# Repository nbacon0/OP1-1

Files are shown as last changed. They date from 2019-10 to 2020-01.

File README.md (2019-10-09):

The OP1:1 project is our effort to address an urgent need in the digital preservation community, namely that optical media (CDs, DVDS, etc.) are almost 40 years old, and are failing at an alarming rate: they're delaminating, suffering from disc rot and a slew of other issues.

Our proposed solution is a (completely open source) device to directly sample the laser as its reading the disc and storing this (very large) raw dump for safe-keeping and process later. The benefit of this approach is that it can be agnostic to the encoding of the discs. The same device that can preserve audio discs could be used to preserve video discs, photo discs, and other proprietary formats.
    
# Current Status
This project is currently months away from an initial release: parts have been ordered by the small group of volunteers and current resources regarding control of the OPU are being slowly assembled from parties that have engaged in research not directly addressing our need, but are still directly applicable to the goals outlined above.

###### Disclaimer
None of the below projects or resources are associated with the OP1:1 Project unless direclty noted.

# Resources

### Links to Projects that Contain Applicable Research and Resources

###### Project #1: Describes & provides a circuit to communicate with three diff. Blu-Ray OPUs

https://www.ncbi.nlm.nih.gov/pmc/articles/PMC6066758/

https://pubs.acs.org/doi/suppl/10.1021/acssensors.8b00340/suppl_file/se8b00340_si_001.pdf

###### Project #2: Reverse engineering the Xbox 360 OPU

http://www.diyouware.com/node/161

https://www.digchip.com/datasheets/parts/datasheet/287/MLX75012.php (photodiode datasheet)

###### Project #3: Controlling blu-ray diode to etch material

https://wiki.das-labor.org/w/LaserExposer

https://github.com/das-labor/laser-exposer

###### Project #4 Bypassing DVD Drive Circuits to Read Raw Data

https://debugmo.de/2007/07/read-your-dvds-the-raw-way/

### Files, Programs & Tools

###### Project 1: Tools & Tool websites used / referenced in OPU Biosensing Paper

https://www.cdspeed2000.com/download.html - Opti Drive Control

http://qpxtool.sourceforge.net/download.html - QPxTools

http://www.k-probe.com/download-kprobe-k-probe.php - K-Probe

###### Project #4 Tools Developed (software library to deal with raw DVD (NRZI) bitstreams.)

https://github.com/tmbinc/libdvd

### Technical Resources

###### Playstation 3 & 4 Blu-Ray Drive Technical Notes

https://www.psdevwiki.com/ps4/Bluray_Drive

https://www.psdevwiki.com/ps3/Bluray_Drive

### Parts List

#### Development Gear
###### Preferred Dev Kit

$57.79 - https://tinyurl.com/y2vp9gc6 - Board (for additional I/O) 

$30.79 - https://tinyurl.com/y5bf4q26 - MCU (WaveShare STM32 Core Board + STM32F7 (8MB of RAM)

###### Breakout Boards

$7.19 - https://tinyurl.com/y5zseyle - Pack of 5 - FPC/FFC Flat Flexible Cable Adapter Board Connectors

$5.69 - https://tinyurl.com/y3howaey - Pack of 5 - FPC/FFC Flat Flexible Cable Adapter Board Connectors 

#### Drives
###### PS3 Drive + OPU

$25.89 - https://tinyurl.com/yxz4hrx3 - PS3 Drive (KEM-410CCA) International Shipping - Drive Option #1

$26.63 - https://tinyurl.com/y2wpv3ua - PS3 Drive (KEM-410CCA) International Shipping - Drive Option #2

$15.90 - https://tinyurl.com/y3cqtx5q - OPU + Sled (KEM-410CCA) International Shipping

$13.50 - https://tinyurl.com/y3bo29z2 - OPU Only (KEM-410CCA) International Shipping

###### Xbox 360 Drive & OPU
$15.50 - $50 (eBay France) - https://tinyurl.com/y4n3xux9 - Xbox 360 HD DVD Drive (international shipping)

 $5.69 - https://tinyurl.com/y4dnyeug - OPU + Sled (PHR-803T) International Shipping

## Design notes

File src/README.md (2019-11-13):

Development platform for OP1:1
==============================

This is out development platform code. It's currently based on `FreeRTOS` and uses ST's HAL library, but this isn't a hard requirement if anybody has other suggestions.

Compiling on Linux
------------------

Only compiling on Linux is supported right now. If anybody wants to make a build system for Windows, that'd be great.

Follow the steps in `COMPILING.md` to install all the necessary tools for the build enviornment.

One you've got everything installed, compiling is as simple as running:
```sh
make
```

If you want to clean and compile the entire project from scratch, run:
```sh
make clean
make
```

To flash the compiled binary onto the dev board, make sure you've got your STLink device plugged in and run:
```sh
make flash
```

Debugging
---------

TODO

FreeRTOS Setup
--------------

We're using `FreeRTOSv10.2.1` and the port from `GCC/ARM_CM7`. Only the minimal amount of files from FreeRTOS has been included, so if there's anything missing, copy it from the FreeRTOS v10.2.1 source.

Currently, the `heap_4.c` memory manager is used, which supports both allocating and freeing. It may not be necessary to use this more complex memory manager, and we could probably use the allocation-only (`heap_1.c`) or basic allocation+free (`heap_2.c`) manager.

References
----------

https://freertos.org/

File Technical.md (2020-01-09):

Technical Work Spec
===================

This document is meant for sharing implementation details and architectural plans for the system.

All information that is finalised should be removed from this document and placed into its own document.

Do not use this document as a reference.

Prototype PCB
-------------

I suggest building the prototype PCB into modules to save on development costs when prototyping.

The following modules are needed:
* Power board
* Coil control board (X, Z and Tilt)
* Focus and Tracking
* Stepper control
* Digital logic

The modules can be connected using a perfboard, direct wiring or a dedicated wiring PCB. For now, we will just build the modules and use direct wiring.

#### Power Board

The power board needs to provide the following voltages:

* +8V
* +5V
* -5V
* +3.3V

The `+8V` is needed by the KEM410 OPU. `+/-5V` are needed by the opamps. `+3.3V` is needed for the digital logic.

We will use a `+12V` barrel jack for input power, and use simple step-down converters to generate the other rails.

#### Coil Control

We can base this on the circuit in the biosensing paper. The biosensing board generates the analouge X, Z and T signals externally, however the voltage is unknown.

#### Focus and Tracking

Can also be based off the biosensing circuit.

#### Stepper control

The IC used in the biosensing circuit is not recommended for new designs. We should make our own circuit for this.

#### Digital logic

The biosensing circuit uses an Atmega168, however the programming is not publicly available. There's no reason to use this part of the biosensing circuit.

Instead, we will use the STM32F7 dev boards.

There's no need to build any custom board for the digital logic control.

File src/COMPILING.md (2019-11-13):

Compiling
=========

Before you can compile, you nees to install the STLink software to communicate with the programmer, as well as the GCC ARM cross compiler.

TODO: `apt install <stuff>`

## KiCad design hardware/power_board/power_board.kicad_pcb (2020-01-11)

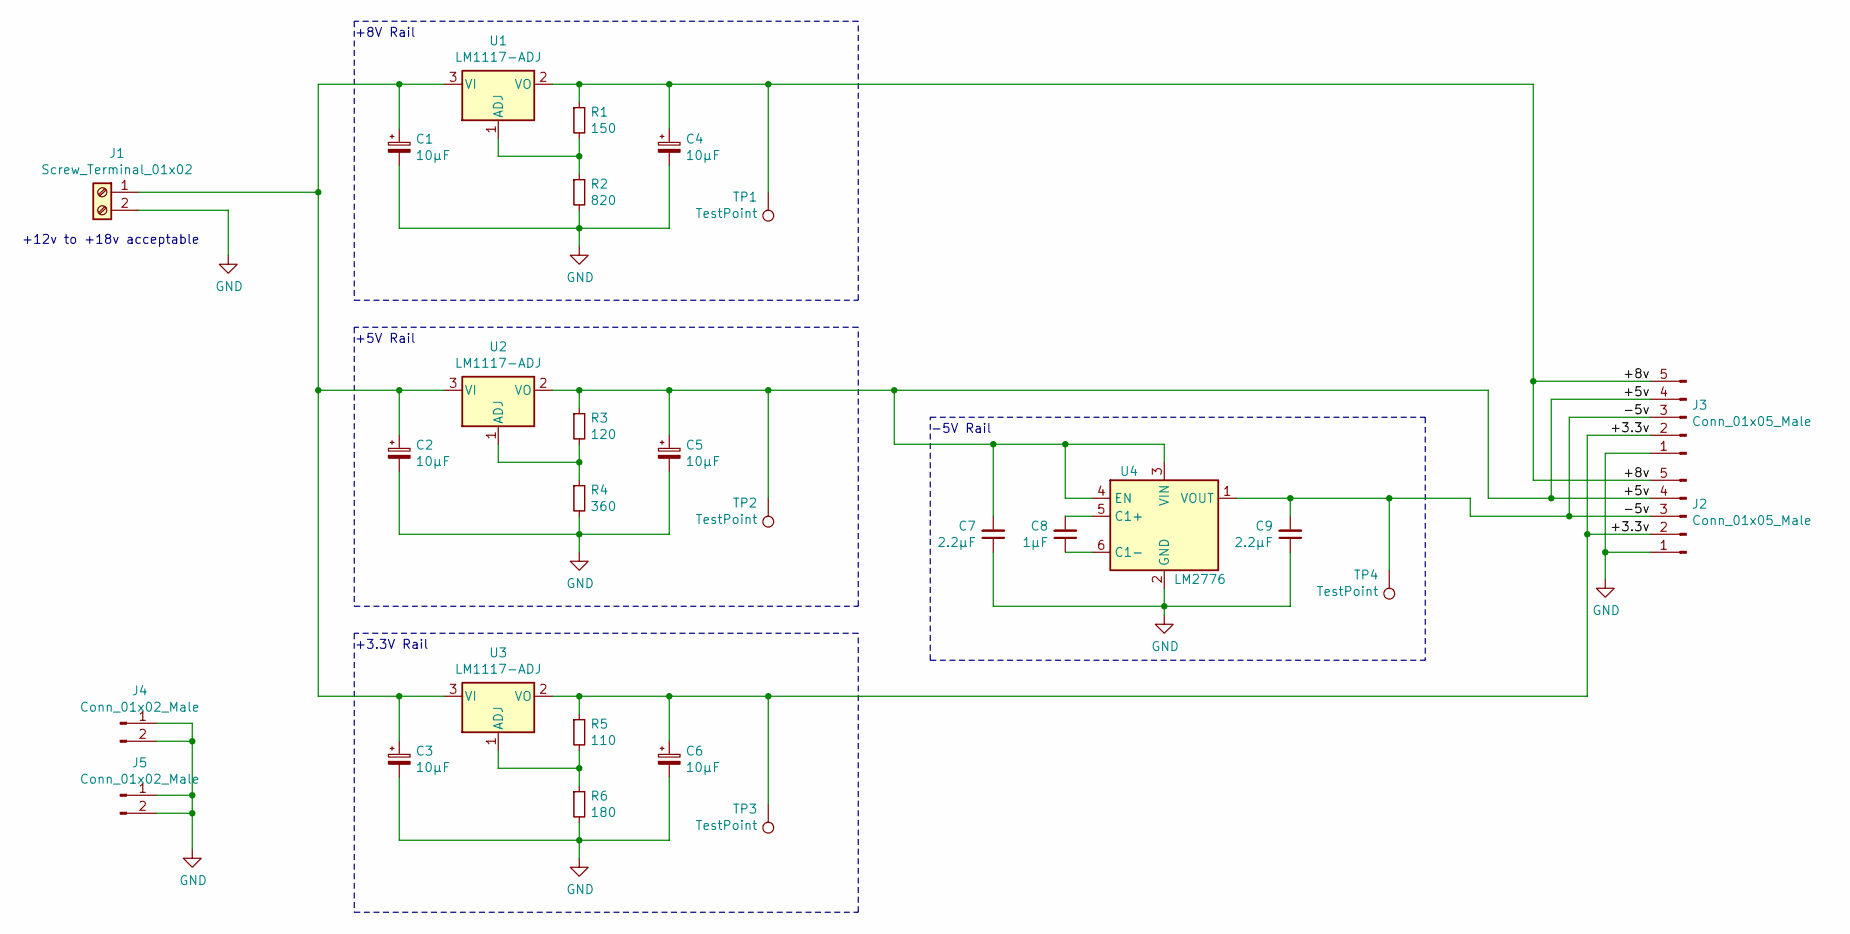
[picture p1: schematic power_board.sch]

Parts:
C1, C2, C3, C4, C5, C6: 10µF; C_1206_3216Metric; LCSC C7171
C7, C9: 2.2µF; C_0603_1608Metric; LCSC C23630
C8: 1µF; C_0603_1608Metric; LCSC C15849
J1: Screw_Terminal_01x02; TerminalBlock_Phoenix_PT-1,5-2-5.0-H_1x02_P5.00mm_Horizontal
J2, J3: Conn_01x05_Male; PinHeader_1x05_P2.54mm_Vertical
J4, J5: Conn_01x02_Male; PinHeader_1x02_P2.54mm_Vertical
R1: 150; R_0603_1608Metric; LCSC C22808
R2: 820; R_0603_1608Metric; LCSC C23253
R3: 120; R_0603_1608Metric; LCSC C22787
R4: 360; R_0603_1608Metric; LCSC C25194
R5: 110; R_0603_1608Metric; LCSC C22781
R6: 180; R_0603_1608Metric; LCSC C22828
TP1, TP2, TP3, TP4: TestPoint; TestPoint_Pad_D1.5mm
U1, U2, U3: LM1117-ADJ; SOT-223-3_TabPin2; LCSC C7920
U4: LM2776; SOT-23-6; LCSC C69527

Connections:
/+3.3v: C6.1, J2.2, J3.2, R5.1, TP3.1, U3.2 (VO)
/+5v: C5.1, C7.2, J2.4, J3.4, R3.1, TP2.1, U2.2 (VO), U4.3 (VIN), U4.4 (EN)
/+8v: C4.1, J2.5, J3.5, R1.1, TP1.1, U1.2 (VO)
/-5v: C9.2, J2.3, J3.3, TP4.1, U4.1 (VOUT)
GND: C1.2, C2.2, C3.2, C4.2, C5.2, C6.2, C7.1, C9.1, J1.2, J2.1, J3.1, J4.1, J4.2, J5.1, J5.2, R2.2, R4.2, R6.2, U4.2 (GND)
unnamed: C1.1, C2.1, C3.1, J1.1, U1.3 (VI), U2.3 (VI), U3.3 (VI)
unnamed: C8.1, U4.6 (C1-)
unnamed: C8.2, U4.5 (C1+)
unnamed: R1.2, R2.1, U1.1 (ADJ)
unnamed: R3.2, R4.1, U2.1 (ADJ)
unnamed: R5.2, R6.1, U3.1 (ADJ)

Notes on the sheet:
+5V Rail
+3.3V Rail
+8V Rail
-5V Rail
+12v to +18v acceptable

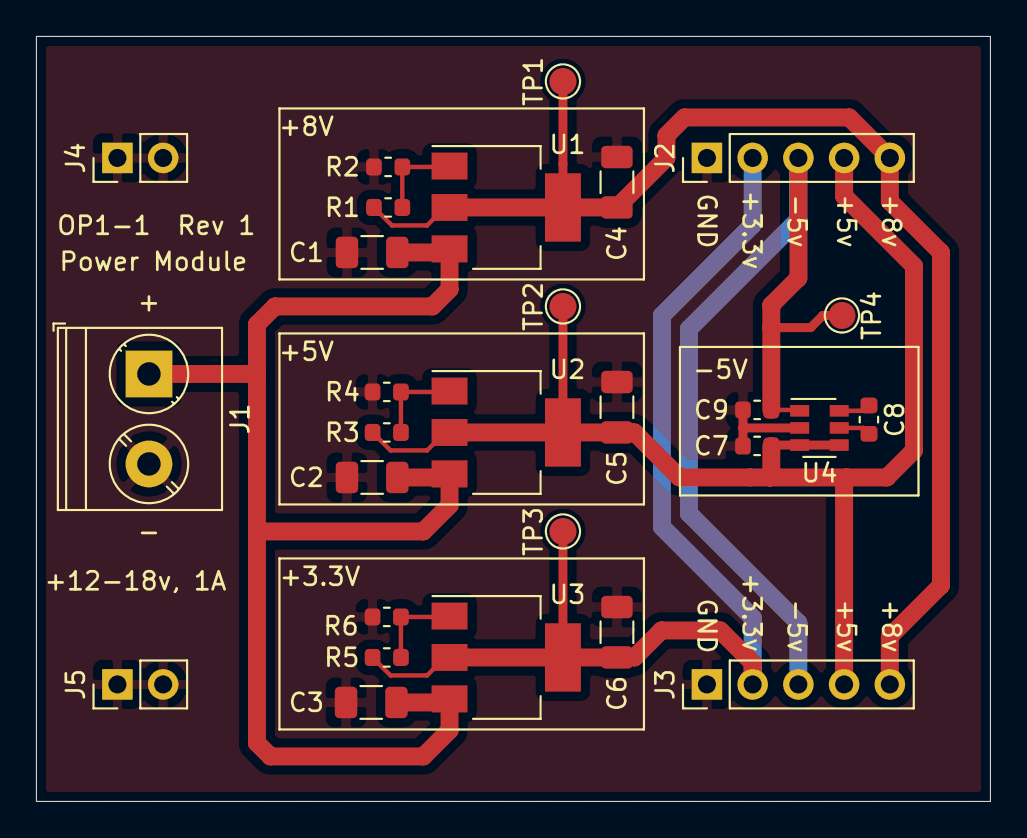
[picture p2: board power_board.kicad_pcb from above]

Board: 2 copper layers, 53.0 x 42.5 mm, 28 parts (0 on the bottom side), 11 nets.

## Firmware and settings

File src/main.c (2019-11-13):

//
//
//
//
//
//

// Scheduler include files.
#include "FreeRTOS.h"
#include "task.h"
#include "timers.h"
#include "semphr.h"

#define QUEUE_LENGTH 1

// The queue used by both tasks.
static QueueHandle_t xQueue = NULL;

// Simple timer
static TimerHandle_t timerHandle;

// Configure the hardware as necessary to run this demo.
static void prvSetupHardware();

// Configure the system clock for maximum speed.
static void prvSystemClockConfig();

// Prototypes for the standard FreeRTOS callback/hook functions implemented within this file.
void vApplicationMallocFailedHook();
void vApplicationIdleHook();
void vApplicationStackOverflowHook( TaskHandle_t pxTask, char *pcTaskName );
void vApplicationTickHook();

// Application spesific prototypes
static void simpleTimerCallback(TimerHandle_t xTimer);

// When something goes terribly wrong, this will set a warning LED and stall
void hardFail()
{
	HAL_GPIO_WritePin(GPIOB, GPIO_PIN_7, GPIO_PIN_SET);
	for(;;);
}

// Main entry point (for C)
int main()
{
	// Configure the hardware ready to run the demo.
	prvSetupHardware();

	// Create the queue
	xQueue = xQueueCreate(QUEUE_LENGTH, sizeof( uint32_t ) );

	if(xQueue == NULL) hardFail();

	long x = 0;
	timerHandle = xTimerCreate(
		"timer1Sec",         // name
		pdMS_TO_TICKS(500), // period/time
		pdTRUE,              // auto reload
		(void*)x,            // Timer ID
		simpleTimerCallback  // Callback
	);

	// Did we manage to make the timer?
	if(timerHandle == NULL) hardFail();

	// Start timer
	if(xTimerStart(timerHandle, x) != pdPASS) hardFail();

	// Start the tasks and timer running.
	vTaskStartScheduler();
	
	/* If all is well, the scheduler will now be running, and the following
	line will never be reached.  If the following line does execute, then
	there was insufficient FreeRTOS heap memory available for the Idle and/or
	timer tasks to be created.  See the memory management section on the
	FreeRTOS web site for more details on the FreeRTOS heap
	http://www.freertos.org/a00111.html. */
	hardFail();

	return 0;
}

static void prvSetupHardware()
{
	GPIO_InitTypeDef  GPIO_InitStruct;

	HAL_Init();

	// Configure Flash prefetch and Instruction cache through ART accelerator.
	#if( ART_ACCLERATOR_ENABLE != 0 )
	{
		__HAL_FLASH_ART_ENABLE();
	}
	#endif // ART_ACCLERATOR_ENABLE

	// Set Interrupt Group Priority
	HAL_NVIC_SetPriorityGrouping(NVIC_PRIORITYGROUP_4);

	// Init the low level hardware.
	HAL_MspInit();

	// Configure the System clock to have a frequency of 200 MHz
	prvSystemClockConfig();

	// Enable GPIOB  Clock (to be able to program the configuration
	// registers) and configure for LED output.
	__GPIOG_CLK_ENABLE();
	__HAL_RCC_GPIOB_CLK_ENABLE();
	__HAL_RCC_GPIOH_CLK_ENABLE();

	GPIO_InitStruct.Pin = GPIO_PIN_6;
	GPIO_InitStruct.Mode = GPIO_MODE_OUTPUT_PP;
	GPIO_InitStruct.Pull = GPIO_PULLUP;
	GPIO_InitStruct.Speed = GPIO_SPEED_HIGH;
	HAL_GPIO_Init(GPIOB, &GPIO_InitStruct);
	HAL_GPIO_WritePin(GPIOB, GPIO_PIN_6, GPIO_PIN_RESET);

	GPIO_InitStruct.Pin = GPIO_PIN_7;
	GPIO_InitStruct.Mode = GPIO_MODE_OUTPUT_PP;
	GPIO_InitStruct.Pull = GPIO_PULLUP;
	GPIO_InitStruct.Speed = GPIO_SPEED_HIGH;
	HAL_GPIO_Init(GPIOB, &GPIO_InitStruct);
	HAL_GPIO_WritePin(GPIOB, GPIO_PIN_7, GPIO_PIN_RESET);

	GPIO_InitStruct.Pin = GPIO_PIN_4;
	GPIO_InitStruct.Mode = GPIO_MODE_OUTPUT_PP;
	GPIO_InitStruct.Pull = GPIO_PULLUP;
	GPIO_InitStruct.Speed = GPIO_SPEED_HIGH;
	HAL_GPIO_Init(GPIOH, &GPIO_InitStruct);
	HAL_GPIO_WritePin(GPIOH, GPIO_PIN_4, GPIO_PIN_RESET);

	// MCO2 : Pin PC9
	HAL_RCC_MCOConfig(RCC_MCO2, RCC_MCO2SOURCE_SYSCLK, RCC_MCODIV_1);
}
/*-----------------------------------------------------------*/

static void prvSystemClockConfig()
{
	RCC_OscInitTypeDef RCC_OscInitStruct;
	RCC_ClkInitTypeDef RCC_ClkInitStruct;

	__PWR_CLK_ENABLE();

	__HAL_PWR_VOLTAGESCALING_CONFIG(PWR_REGULATOR_VOLTAGE_SCALE1);

	RCC_OscInitStruct.OscillatorType = RCC_OSCILLATORTYPE_HSE;
	RCC_OscInitStruct.HSEState = RCC_HSE_ON;
	RCC_OscInitStruct.PLL.PLLState = RCC_PLL_ON;
	RCC_OscInitStruct.PLL.PLLSource = RCC_PLLSOURCE_HSE;
	RCC_OscInitStruct.PLL.PLLM = 8;
	RCC_OscInitStruct.PLL.PLLN = 432;
	RCC_OscInitStruct.PLL.PLLP = RCC_PLLP_DIV2;
	RCC_OscInitStruct.PLL.PLLQ = 7;
	HAL_RCC_OscConfig(&RCC_OscInitStruct);

	HAL_PWREx_ActivateOverDrive();

	RCC_ClkInitStruct.ClockType = RCC_CLOCKTYPE_HCLK|RCC_CLOCKTYPE_SYSCLK
	                          |RCC_CLOCKTYPE_PCLK1|RCC_CLOCKTYPE_PCLK2;
	RCC_ClkInitStruct.SYSCLKSource = RCC_SYSCLKSOURCE_PLLCLK;
	RCC_ClkInitStruct.AHBCLKDivider = RCC_SYSCLK_DIV1;
	RCC_ClkInitStruct.APB1CLKDivider = RCC_HCLK_DIV4;
	RCC_ClkInitStruct.APB2CLKDivider = RCC_HCLK_DIV2;
	HAL_RCC_ClockConfig(&RCC_ClkInitStruct, FLASH_LATENCY_7);

	HAL_SYSTICK_Config(HAL_RCC_GetHCLKFreq()/1000);

	HAL_SYSTICK_CLKSourceConfig(SYSTICK_CLKSOURCE_HCLK);

	/* SysTick_IRQn interrupt configuration */
	HAL_NVIC_SetPriority(SysTick_IRQn, 15, 0);
}
/*-----------------------------------------------------------*/

void vApplicationMallocFailedHook()
{
	/* Called if a call to pvPortMalloc() fails because there is insufficient
	free memory available in the FreeRTOS heap.  pvPortMalloc() is called
	internally by FreeRTOS API functions that create tasks, queues, software
	timers, and semaphores.  The size of the FreeRTOS heap is set by the
	configTOTAL_HEAP_SIZE configuration constant in FreeRTOSConfig.h. */

	// Force an assert.
	configASSERT((volatile void*) NULL);
}
/*-----------------------------------------------------------*/

void vApplicationStackOverflowHook(TaskHandle_t pxTask, char *pcTaskName)
{
	(void) pcTaskName;
	(void) pxTask;

	/* Run time stack overflow checking is performed if
	configCHECK_FOR_STACK_OVERFLOW is defined to 1 or 2.  This hook
	function is called if a stack overflow is detected. */

	/* Force an assert. */
	configASSERT((volatile void*) NULL);
}
/*-----------------------------------------------------------*/

void vApplicationIdleHook()
{
	volatile size_t xFreeHeapSpace;

	/* This is just a trivial example of an idle hook.  It is called on each
	cycle of the idle task.  It must *NOT* attempt to block.  In this case the
	idle task just queries the amount of FreeRTOS heap that remains.  See the
	memory management section on the http://www.FreeRTOS.org web site for memory
	management options.  If there is a lot of heap memory free then the
	configTOTAL_HEAP_SIZE value in FreeRTOSConfig.h can be reduced to free up
	RAM. */
	xFreeHeapSpace = xPortGetFreeHeapSize();

	/* Remove compiler warning about xFreeHeapSpace being set but never used. */
	(void) xFreeHeapSpace;
}
/*-----------------------------------------------------------*/

void vAssertCalled(uint32_t ulLine, const char *pcFile)
{
	volatile unsigned long ul = 0;

	(void) pcFile;
	(void) ulLine;

	HAL_GPIO_WritePin(GPIOB, GPIO_PIN_7, GPIO_PIN_SET);

	taskENTER_CRITICAL();
	{
		/* Set ul to a non-zero value using the debugger to step out of this
		function. */
		while(ul == 0)
		{
			__NOP();
		}
	}
	taskEXIT_CRITICAL();
}
/*-----------------------------------------------------------*/

void vApplicationTickHook()
{

}
/*-----------------------------------------------------------*/

static void simpleTimerCallback(TimerHandle_t xTimer)
{
	HAL_GPIO_TogglePin(GPIOB, GPIO_PIN_6);
}

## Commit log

2020-01-09 Added the biosensing schematic, with some annotations
2020-01-11 Added power board module
    [power_board.kicad_pcb, power_board.sch]
2020-01-11 Made the board design a little more spacious
    [power_board.kicad_pcb, power_board.sch]
